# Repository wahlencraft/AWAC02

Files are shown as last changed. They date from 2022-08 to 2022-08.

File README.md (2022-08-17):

# AWAC02
An alarm clock made from scratch. The main components are ATmega328P, 2 Sparkfun Qwiic Alphanumeric Display and MCP7940M RTC. 

Work in progress. Current functionality includes:

- Show the time in 3 different formats
    - `  HH MM:SS`
    - `DDD  HH:MM`
    - `20YY MM:DD`
- Use the buttons to open a menu.
    - Change display brightness
    - Set time

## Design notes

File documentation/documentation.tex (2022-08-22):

\documentclass{awac02}

% Packages
\usepackage[utf8]{inputenc}
\usepackage{tabularx}
\usepackage{graphicx}
\usepackage{svg}
\input{tikzconfig}

\title{Documentation}
\begin{document}

\maketitle

\section{Overview}

The documentation is meant as a guide for the developer. Additional aid is
found in the source header files where most functions are documented.

\section{Source Files}

In this section an overview of the project files are given.
The files are listed in order of relevance.

\begin{centering}
\vspace{3mm}
\begin{tabularx}{.9\textwidth}{ >\raggedright p{5cm} | X }
    File(s)                  & Description \\ [0.5ex]
    \hline
    \texttt{main.c}                     & The main file. Contains the
                                          clock-mode state-machine.\\
    \texttt{constants.h}                & Global constants for defining number
                                          of displays, enabling logging etc. \\
    \texttt{menu.h}, \texttt{menu.c}    & The state machine for the menu. \\
    \texttt{utilities.h}, \texttt{utilities.c} & High level utilities. Mostly
                    for applying and showing settings. \\
    \texttt{log.h}, \texttt{log.c}      & Logging functions. Everything here
                                          will be unavailable if the LOG
                                          constant is undefined. \\
    \texttt{rtc.h}, \texttt{rtc.c}      & High level functions to set and show
                                          the external RTC clock. \\
    \texttt{display.h}, \texttt{display.c} & Low level functions to interface
                                             with the Qwiic Alphanumeric Display \\
    \texttt{helpers.h}, \texttt{helpers.c} & Simple helper-functions. \\
    \texttt{external\_interrupts.h}, \texttt{external\_interrupts.S} &
                    Register and extract the external interrupts (button
                    presses and RTC alarms). \\
    \texttt{time.h}, \texttt{time.S}    & Start and use the hardware times. \\
    \texttt{sleep.h}, \texttt{sleep.S}  & Set the processor sleep state. \\
    \texttt{twi.h}, \texttt{twi.S}      & Interface to the TWI (I2C) hardware.
                                          Read and write to external devices. \\
    \texttt{eeprom.h}, \texttt{eeprom.S} & Read and write to the EEPROM
                                           (non-volatile storage). \\
    \texttt{flash.h}, \texttt{flash.S}  & Read constant data from flash. For
                                          example an ASCII conversion table. \\
    \texttt{io.h}, \texttt{io.S}        & Direct control of pins. \\
    \texttt{usart.h}, \texttt{usart.S}  & Send data through USART. This is used
                                          to implement printf in `log.c` \\
    \texttt{math.S}                     & Low level math for assembly routines.
\end{tabularx}
\end{centering}

\section{Schematic}

In figure \ref{fig:circuit} the circuit is shown. The value of R1-R7, C1 and C5-C7
is only approximate. You can try different values. In addition to these
components two Sparkfun Qwiic Alphanumeric Displays are used. One of the
displays must be modified to disable the pull-up resistors and change the slave
address to \texttt{0x71}.

\begin{figure}[h]
    \centering
    
    \caption{The circuit (excluding displays).}
    \label{fig:circuit}
\end{figure}

\section{State Machine}

The state machine for clock mode is in \texttt{main.c} and the state machine
for the menu mode is in \texttt{menu.c}. They are implemented using the
\texttt{goto} statement which can lead to hard to understand code.  To give the
programmer a better overview of the states and make development easier some
states are documented here and shown in flow-charts. The program starts in the
\texttt{enter\_clock\_mode} state. The clock mode state machine is illustrated
in Figure \ref{fig:clock-state}.

\begin{figure}[h]
    \centering
    \input{clock-state}
    \caption{The clock mode state machine}
    \label{fig:clock-state}
\end{figure}

The menu mode state machine is a bit more complicated. A simple overview is
shown in Figure \ref{fig:menu-flowchart}. There are three basic state types in the
menu. \emph{Menu} states, \emph{choose} states and \emph{set} states. The menu
states are very simple. Each show some text on the display, then wait for a
button interrupt. If the \texttt{L} or \texttt{R} button is pressed the
state is changed to the previous or next menu state. If the \texttt{SP} button
is pressed it is changed to a choose or set state.

A choose state is used when there is multiple options for the setting that is
edited. For example when changing time. A choose state first shows the current
value of that setting, sets an RTC alarm for when it is changed and waits for
an interrupt. If the interrupt is from the RTC the new value is shown. If it is
from the \texttt{L} or \texttt{R} buttons the state changes to the previous or
next choose state. If it is from the \texttt{SP} button the state changes to
the corresponding set state.

A set state works a lot like a choose state. A RTC interrupt changes the value
shown and \texttt{SP} interrupt changes state (go back to the choose state).
But a \texttt{L} or \texttt{R} button interrupt de- or increments the value
instead.

Figure \ref{fig:choose-and-set-state} shows the program flow between a choose
and a set state in detail. The actual implementation varies slightly
between types.

\begin{figure}[h]
    \centering
    \input{choose-and-set-state}
    \caption{A choose and set state combo}
    \label{fig:choose-and-set-state}
\end{figure}

\begin{figure}[h]
    \centering
    \input{menu-flowchart}
    \label{fig:menu-flowchart}
    \caption{An overview of the menu}
\end{figure}

\end{document}

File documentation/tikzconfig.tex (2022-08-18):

\usepackage{tikz}
\usepackage{xparse}
\usetikzlibrary{positioning, fit, backgrounds, shapes, arrows.meta}

% State machine

\tikzstyle{start} = [rectangle, rounded corners, minimum width=3cm, text centered,
 draw=black, fill=red!30, inner sep=1em]

\tikzstyle{io} = [trapezium, trapezium left angle=70, trapezium right angle=110, 
 minimum height=1cm, text centered, draw=black, fill=blue!30, trapezium stretches=true,
 align=center, inner sep=1em] 

\tikzstyle{state} = [rectangle, minimum height=1cm, align=center,
      draw=black, fill=orange!30, inner sep=1em]

\tikzstyle{decision} = [ellipse, minimum width=3cm, minimum height=1cm, text centered, draw=black,
 fill=green!30, inner sep=.5em]

\tikzstyle{subprocess} = [rectangle, draw = black!50, minimum height = 2em, fill=pink!50]

\tikzstyle{process2} = [rectangle, minimum height=1cm, align=center, draw=black, fill=yellow!30, inner sep=1.8em]

\tikzstyle{process_label} = [external/.style={draw=black!50}, font={\fontsize{13pt}{12}\selectfont}]

\tikzstyle{arrow} = [thick,->,>=stealth]
\tikzstyle{slow_arrow} = [dotted, thick,->,>=stealth]
\tikzstyle{line} = [thick]

\NewDocumentCommand\StateWithBullets{m m m >{\SplitList{;}}m}{%
    \node (#1) [state, text width=6cm, #2, inner sep=5pt] {\large #3\small \begin{itemize}
    \ProcessList{#4}{\insertitem} \end{itemize}};
}
\newcommand\insertitem[1]{\item #1}

\NewDocumentCommand\JustBullets{m m >{\SplitList{;}}m}{%
    \node (#1) [state, text width=3.5cm, #2, inner sep=5pt, rounded corners,
    fill=blue!30] {\vspace{-0.8em}\small\begin{itemize}
    \ProcessList{#3}{\insertitem} \end{itemize}};
}

% Distances
\newcommand{\shortarrowlength}{3.1em}

% Menu
\tikzstyle{menu-base} = [text centered, draw=black, inner sep=0.5em, node
distance=4em, minimum height=3em, minimum width=9em]

\tikzstyle{menu-enterexit} = [menu-base, rectangle, rounded corners, fill=black!10]

\tikzstyle{menu-item} = [menu-base, rectangle, rounded corners, minimum height=3.5em]

\tikzstyle{menu-small-item} = [menu-base, rectangle, rounded corners, minimum
width=4em, minimum height=2em]

\tikzstyle{menu-setting} = [menu-base, rectangle, rounded corners, minimum
width=7em]

\tikzstyle{button-label} = [circle, draw=black, minimum size=1.3em, fill=white, inner
sep=0, line width=0.5pt, font=\footnotesize]

\tikzstyle{menu-single} = [->, >={Latex[length=2mm, width=3mm]}, line width=4pt]
\tikzstyle{menu-double} = [menu-single, <->]

\newcommand{\LRvert}[2]{%
    \draw[menu-single] ([xshift=1em]#1.south) -- node[button-label] {R}
        ([xshift=1em]#2.north);
    \draw[menu-single] ([xshift=-1em]#2.north) -- node[button-label] {L}
        ([xshift=-1em]#1.south);
}

\newcommand{\LRhor}[2]{%
    \draw[menu-single] ([yshift=0.5em]#1.east) -- node[button-label] {R}
        ([yshift=0.5em]#2.west);
    \draw[menu-single] ([yshift=-0.5em]#2.west) -- node[button-label] {L}
        ([yshift=-0.5em]#1.east);
}

\newcommand{\IncrementDecrementNode}[2]{%
    \node (_#2anchor) [#1=\shortarrowlength+1.3em of #2, outer sep=1pt, inner sep=0] {};
    \node (_#2L) [button-label, above left=0.2em of _#2anchor] {L};
    \node (_#2dec) [below left=0.2em of _#2anchor, inner sep=0, circle, minimum size=1.3em] {--};
    \node (_#2R) [button-label, above right=0.2em of _#2anchor] {R};
    \node (_#2inc) [below right=0.2em of _#2anchor, inner sep=0, circle, minimum size=1.3em] {+};
    \node (_#2set) [fit={(_#2L) (_#2R) (_#2dec) (_#2inc)}, draw] {};
}

\newcommand{\SetTimeNode}[3]{%
    \node (#1) [#2, menu-small-item] {#3};
    \IncrementDecrementNode{below}{#1}
    \draw[menu-double] (#1) -- node[button-label] {SP} (_#1set.north);
}

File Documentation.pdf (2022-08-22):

# AWAC02

# Documentation

AWAC02 | Documentation

## 1 Overview

The documentation is meant as a guide for the developer. Additional aid is found in the source header files where most functions are documented.

1

AWAC02 | Documentation

## 2 Source Files

In this section an overview of the project files are given. The files are listed in order of relevance.

File(s) | Description
main.c | The main file. Contains the clock-mode state-machine.
constants.h | Global constants for defining number of displays, enabling
| logging etc.
menu.h, menu.c | The state machine for the menu.
utilities.h, utilities.c | High level utilities. Mostly for applying and showing set-
| tings.
log.h, log.c | Logging functions. Everything here will be unavailable if
| the LOG constant is undefined.
rtc.h, rtc.c | High level functions to set and show the external RTC clock.
display.h, display.c | Low level functions to interface with the Qwiic Alphanu-
| meric Display
helpers.h, helpers.c | Simple helper-functions.
external interrupts.h, external interrupts.S | Register and extract the external interrupts (button presses
| and RTC alarms).
time.h, time.S | Start and use the hardware times.
sleep.h, sleep.S | Set the processor sleep state.
twi.h, twi.S | Interface to the TWI (I2C) hardware. Read and write to
| external devices.
eeprom.h, eeprom.S | Read and write to the EEPROM (non-volatile storage).
flash.h, flash.S | Read constant data from flash. For example an ASCII con-
| version table.
io.h, io.S | Direct control of pins.
usart.h, usart.S | Send data through USART. This is used to implement
| printf in ‘log.c‘
math.S | Low level math for assembly routines.

2

## 3 Schematic

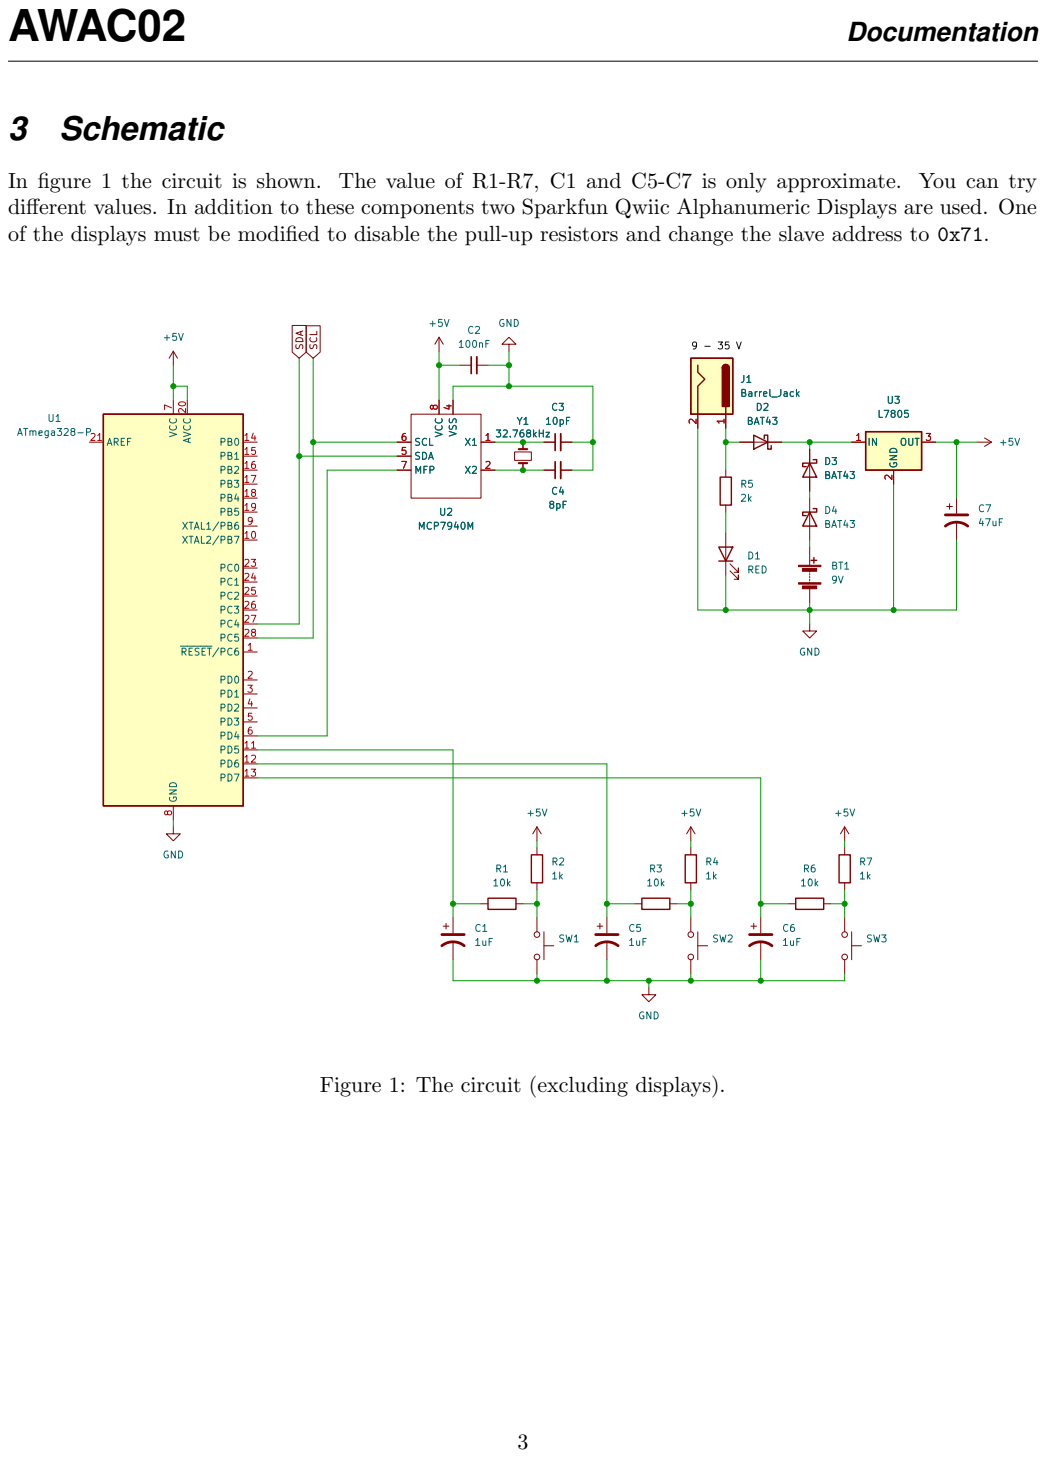
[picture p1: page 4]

In figure 1 the circuit is shown. The value of R1-R7, C1 and C5-C7 is only approximate. You can try
different values. In addition to these components two Sparkfun Qwiic Alphanumeric Displays are used. One
of the displays must be modified to disable the pull-up resistors and change the slave address to 0x71.

4 SDA 5 SCL 6 MFP 7 VCC

Figure 1: The circuit (excluding displays).

AWAC02 | Documentation

## 4 State Machine

The state machine for clock mode is in main.c and the state machine for the menu mode is in menu.c. They are implemented using the goto statement which can lead to hard to understand code. To give the programmer a better overview of the states and make development easier some states are documented here and shown in flow-charts. The program starts in the enter clock mode state. The clock mode state machine

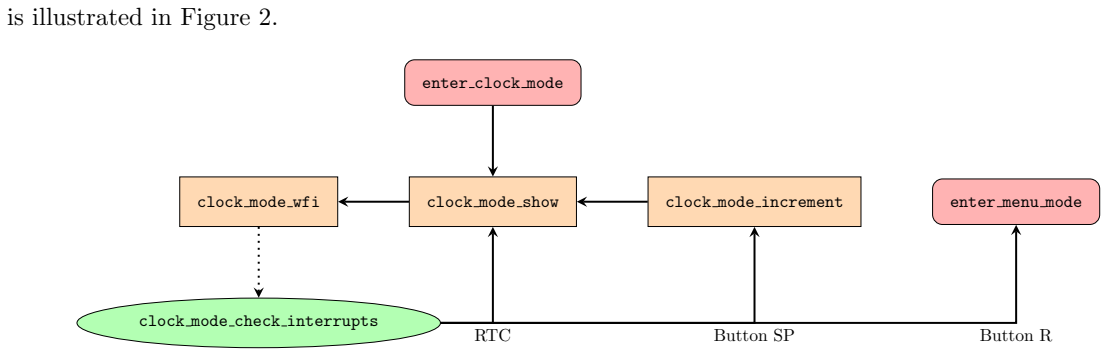
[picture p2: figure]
is illustrated in Figure 2.; clock mode show; enter clock mode; clock mode wfi; clock mode increment; clock mode check interrupts; enter menu mode; RTC; Button SP; Button R

Figure 2: The clock mode state machine

The menu mode state machine is a bit more complicated. A simple overview is shown in Figure 4. There are three basic state types in the menu. Menu states, choose states and set states. The menu states are very simple. Each show some text on the display, then wait for a button interrupt. If the L or R button is pressed the state is changed to the previous or next menu state. If the SP button is pressed it is changed to a choose or set state.
A choose state is used when there is multiple options for the setting that is edited. For example when changing time. A choose state first shows the current value of that setting, sets an RTC alarm for when it is changed and waits for an interrupt. If the interrupt is from the RTC the new value is shown. If it is from the L or R buttons the state changes to the previous or next choose state. If it is from the SP button the state changes to the corresponding set state.
A set state works a lot like a choose state. A RTC interrupt changes the value shown and SP interrupt changes state (go back to the choose state). But a L or R button interrupt de- or increments the value instead.
Figure 3 shows the program flow between a choose and a set state in detail. The actual implementation varies slightly between types.

4

AWAC02 | Documentation

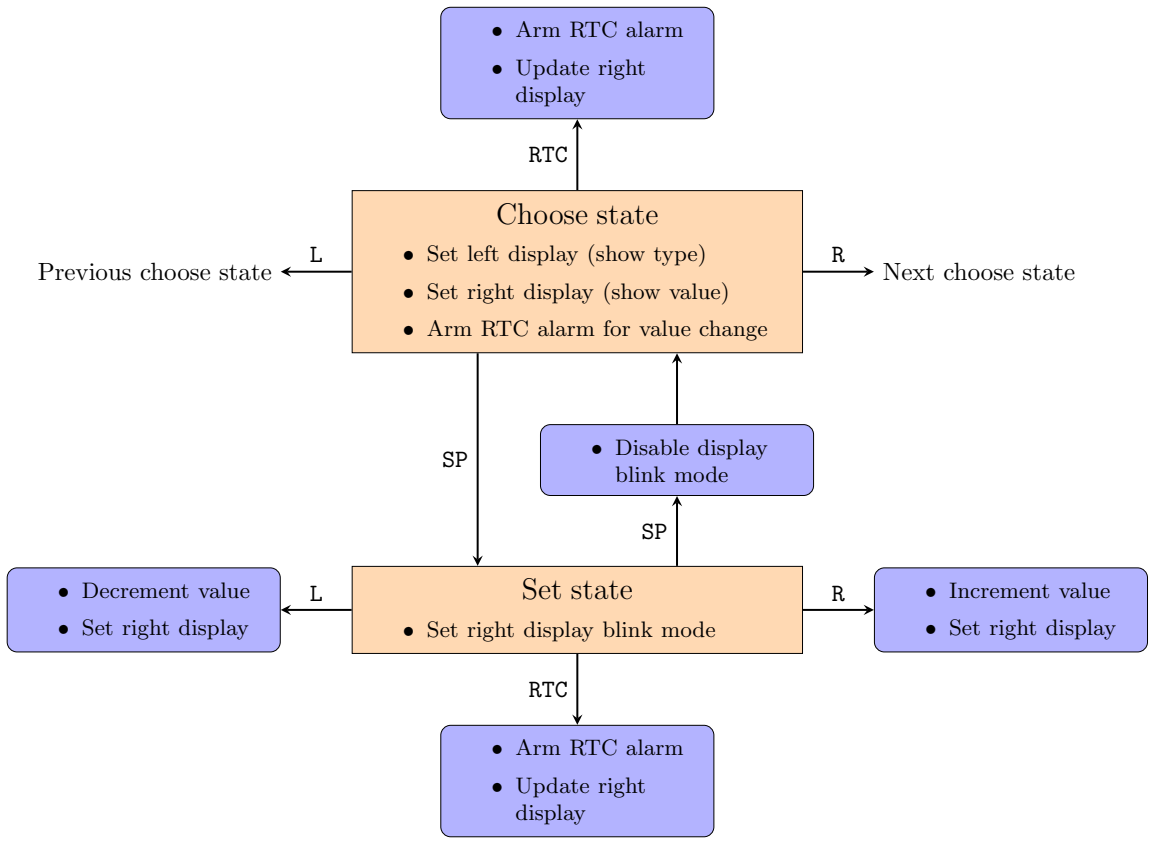
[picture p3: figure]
Choose state; • Set left display (show type); • Set right display (show value); • Arm RTC alarm for value change; • Arm RTC alarm; • Update right; display; • Disable display; blink mode; Set state; • Set right display blink mode; Previous choose state; Next choose state; • Decrement value; • Set right display; • Increment value; RTC

Figure 3: A choose and set state combo

5

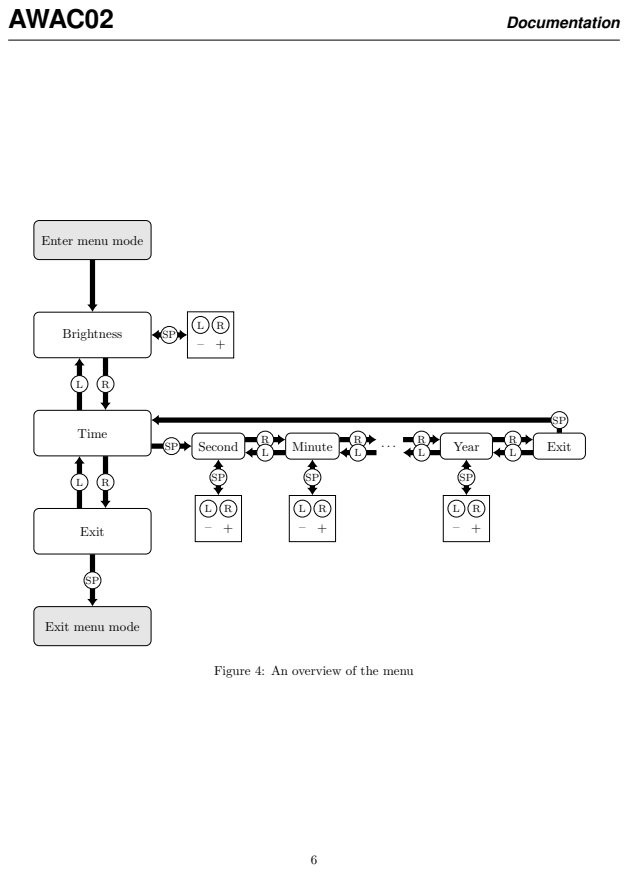
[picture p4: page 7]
AWAC02; Documentation; Brightness; Time; Exit; Second; Minute; Year; Exit R L

Enter menu mode

Exit menu mode

Figure 4: An overview of the menu

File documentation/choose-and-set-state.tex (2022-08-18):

\begin{tikzpicture}[every node/.style={scale=1}]

\StateWithBullets{CHOOSE}{draw}{Choose state}{Set left display (show type);Set
    right display (show value);Arm
RTC alarm for value change}

\JustBullets{RTC1}{above=of CHOOSE}{Arm RTC alarm; Update right display}

\JustBullets{SET_DONE}{below=of CHOOSE, xshift=4em}{Disable display blink mode}

\StateWithBullets{SET}{below=3 of CHOOSE}{Set state}{Set right display blink mode}

\node (PREVIOUS) [left=of CHOOSE] {Previous choose state};
\node (NEXT) [right=of CHOOSE] {Next choose state};

\JustBullets{DEC}{left=of SET}{Decrement value;Set right display}
\JustBullets{INC}{right=of SET}{Increment value;Set right display}
%\node (INC) [right=of SET, text width=8em] {Increment value, \\ Set right display};

\JustBullets{RTC2}{below=of SET}{Arm RTC alarm; Update right display}

% Arrows
\draw[arrow] (CHOOSE) -- node[anchor=south] {\texttt{L}} (PREVIOUS);
\draw[arrow] (CHOOSE) -- node[anchor=south] {\texttt{R}} (NEXT);
\draw[arrow] (CHOOSE) -- node[anchor=east] {\texttt{RTC}} (RTC1);

\draw[arrow] ([xshift=-4em]CHOOSE.south) -- node[anchor=east] {\texttt{SP}}
    ([xshift=-4em]SET.north);

\draw[arrow] ([xshift=4em]SET.north) -- node[anchor=east] {\texttt{SP}}
    (SET_DONE.south);
\draw[arrow] (SET_DONE.north) -- ([xshift=4em]CHOOSE.south);

\draw[arrow] (SET) -- node[anchor=south] {\texttt{L}} (DEC);
\draw[arrow] (SET) -- node[anchor=south] {\texttt{R}} (INC);
\draw[arrow] (SET) -- node[anchor=east] {\texttt{RTC}} (RTC2);

%\node (TESTNODE) [draw, text width=3cm] {Hejsvejs \newline $\bullet$ title};

%\node [font=\Large] (top)    at (5,10) {Choose state};
%\node [font=\Large] (middle) at (5,9)  {$\bullet$ [1]};
%\node [font=\Large] (bottom) at (5,8)  {$\bullet$ [2]};
%\node[draw=brown, thick,fit={(top) (middle) (bottom)}, inner sep=10pt]   (box) {};

\end{tikzpicture}

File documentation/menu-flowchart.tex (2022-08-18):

\begin{tikzpicture}[every node/.style={scale=1}]

\node (ENTER_MENU_MODE) [menu-enterexit] { Enter menu mode };

\node (MENU_BRIGHTNESS) [menu-item, below=of ENTER_MENU_MODE] { Brightness };

\IncrementDecrementNode{right}{MENU_BRIGHTNESS}
%\node(SET_BRIGHTNESS) [menu-setting, right=of MENU_BRIGHTNESS] { Set Brightness };

\node(MENU_TIME) [menu-item, below=of MENU_BRIGHTNESS] { Time };

\node(MENU_EXIT) [menu-item, below=of MENU_TIME] { Exit };

\node(EXIT_MENU_MODE) [menu-enterexit, below=of MENU_EXIT] { Exit menu mode };

% Time

\SetTimeNode{SET_SECOND}{right=\shortarrowlength of MENU_TIME,yshift=-1em}{Second};
\SetTimeNode{SET_MINUTE}{right=\shortarrowlength of SET_SECOND}{Minute};

\node (SET_DOTDOTDOT) [right=of SET_MINUTE]{\dots};

\SetTimeNode{SET_YEAR}{right=of SET_DOTDOTDOT}{Year};

\node (SET_EXIT) [menu-small-item, right=\shortarrowlength of SET_YEAR] {Exit};

% Time arrows
\LRhor{SET_SECOND}{SET_MINUTE}
\LRhor{SET_MINUTE}{SET_DOTDOTDOT}
\LRhor{SET_DOTDOTDOT}{SET_YEAR}
\LRhor{SET_YEAR}{SET_EXIT}

% Arrows between menu items
\draw[menu-single] (ENTER_MENU_MODE) -- (MENU_BRIGHTNESS);

\LRvert{MENU_BRIGHTNESS}{MENU_TIME}
\LRvert{MENU_TIME}{MENU_EXIT}

\draw[menu-single] (MENU_EXIT) -- node[button-label] {SP} (EXIT_MENU_MODE);

% Arrows to set brightness items
\draw[menu-double] (MENU_BRIGHTNESS) -- node[button-label] {SP} (_MENU_BRIGHTNESSset);

% Arrows to set time items
\draw[menu-single] ([yshift=-1em]MENU_TIME.east) -- node[button-label] {SP} (SET_SECOND);

\draw[menu-single] (SET_EXIT.north) |- node[button-label] {SP} ([yshift=1em]MENU_TIME.east);

\end{tikzpicture}

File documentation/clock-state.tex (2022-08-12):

\begin{tikzpicture}[every node/.style={scale=0.7}]

\node (CLOCK_MODE_SHOW) [state] { \texttt{clock\_mode\_show}};
\node (ENTER_CLOCK_MODE) [start, above=of CLOCK_MODE_SHOW] {\texttt{enter\_clock\_mode}};
\node (CLOCK_MODE_INCREMENT) [state, right=of CLOCK_MODE_SHOW] {\texttt{clock\_mode\_increment}};
\node (CLOCK_MODE_WFI) [state, left=of CLOCK_MODE_SHOW] {\texttt{clock\_mode\_wfi}};
\node (CLOCK_MODE_CHECK_INTERRUPTS) [decision, below=of CLOCK_MODE_WFI] {\texttt{clock\_mode\_check\_interrupts}};
\node (ENTER_MENU_MODE) [start, right=of CLOCK_MODE_INCREMENT] {\texttt{enter\_menu\_mode}};

\draw [arrow] (ENTER_CLOCK_MODE) -- (CLOCK_MODE_SHOW);

\draw [arrow] (CLOCK_MODE_CHECK_INTERRUPTS) -| node[anchor=north]{RTC}
    (CLOCK_MODE_SHOW);
\draw [arrow] (CLOCK_MODE_CHECK_INTERRUPTS) -| node[anchor=north]{Button SP} (CLOCK_MODE_INCREMENT);
\draw [arrow] (CLOCK_MODE_CHECK_INTERRUPTS) -| node[anchor=north]{Button R} (ENTER_MENU_MODE);

\draw [arrow] (CLOCK_MODE_SHOW) -- (CLOCK_MODE_WFI);
\draw [arrow] (CLOCK_MODE_INCREMENT) -- (CLOCK_MODE_SHOW);
\draw [slow_arrow] (CLOCK_MODE_WFI) -- (CLOCK_MODE_CHECK_INTERRUPTS);

\end{tikzpicture}

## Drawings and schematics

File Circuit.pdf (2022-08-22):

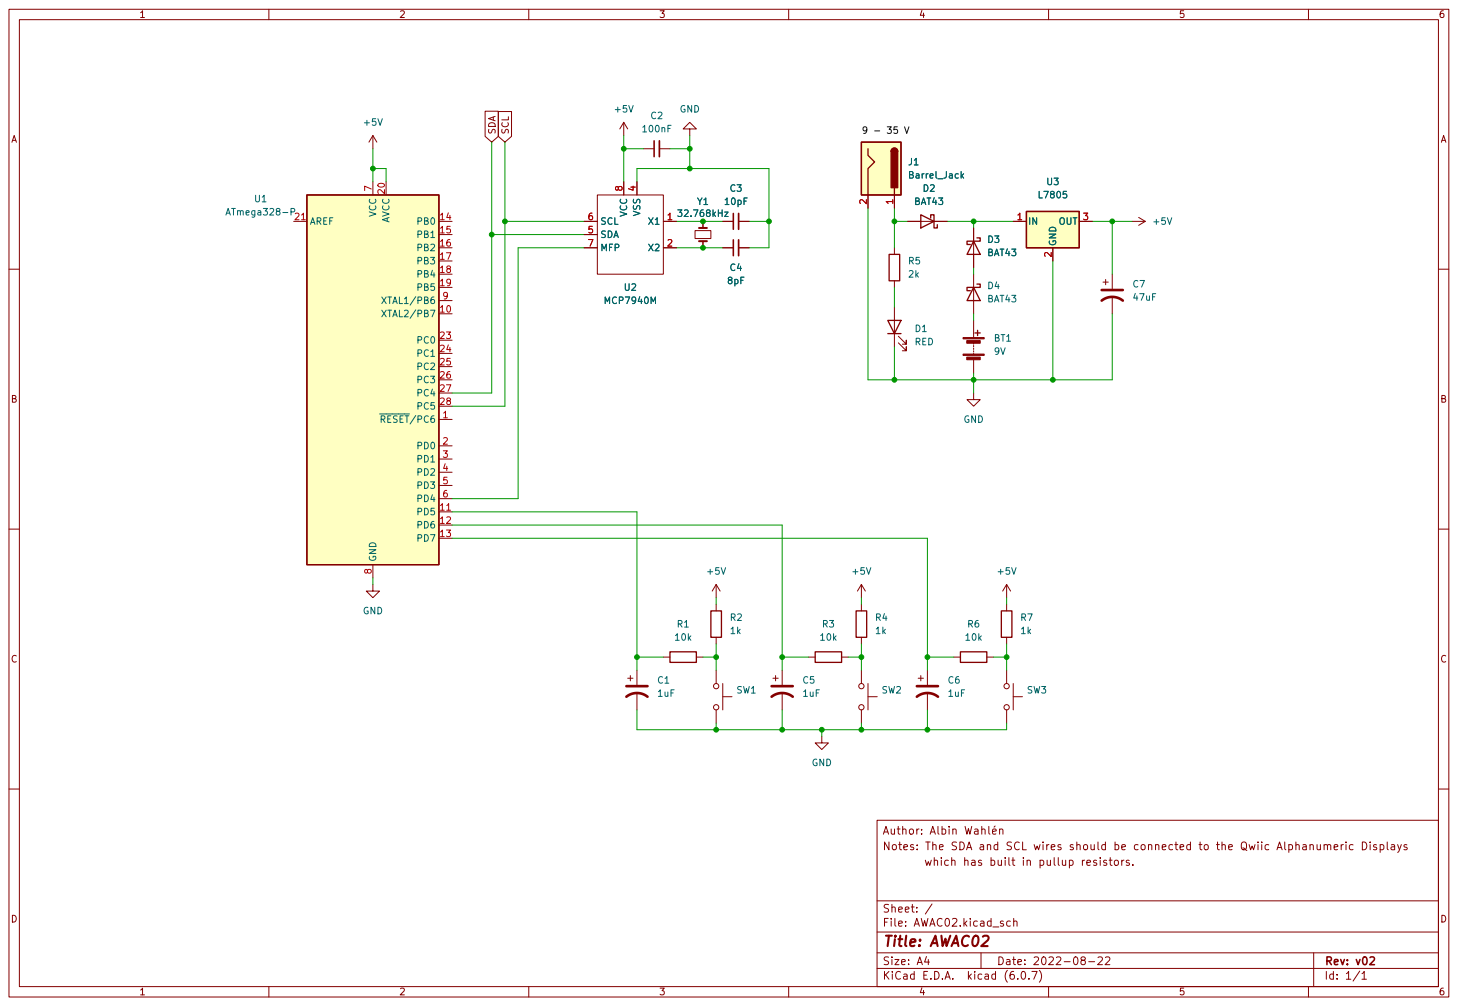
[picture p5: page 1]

4 SDA 5 SCL 6 MFP 7 VCC

Notes: The SDA and SCL wires should be connected to the Qwiic Alphanumeric Displays
which has built in pullup resistors.

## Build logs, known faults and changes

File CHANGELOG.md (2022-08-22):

# Changelog

## [0.2.0] -- 2022-08-22
### Added
- Button input
- EEPROM read/write (non-volatile storage)
- Clock mode, show the time in one of three formats:
    - `  HH MM:SS`
    - `DDD  HH:MM`
    - `20YY MM:DD`
- Menu mode:
    - Set display brightness
    - Set clock

### Changed
- The documentation is now written in LaTeX

## [0.1.0] -- 2022-07-31
### Added
- Show hours minutes and seconds since power-on.
- Backend functions to manage the display and clock.
- A schematic.

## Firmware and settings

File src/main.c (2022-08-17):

#include <stdint.h>
#include <avr/io.h>
#include <avr/interrupt.h>

#include "usart.h"
#include "time.h"
#include "io.h"
#include "twi.h"
#include "log.h"
#include "flash.h"
#include "display.h"
#include "rtc.h"
#include "external_interrupts.h"
#include "eeprom.h"
#include "sleep.h"
#include "menu.h"
#include "utilities.h"

#include "helpers.h"

extern volatile uint8_t irc_counter;

int main(void) {
    init_log(INFO | ERROR | WARNING | RTC | STATE);

    start_counter0();
    start_counter1();
    sei();

    enable();

    TWI_init();

    sleep_ms1(1);

    initiate_all_displays();
    sleep_ms1(10);

    log(INFO, "Start program\n");

    set_display_buffer_long_string("STRTPRGM", 8);
    write_to_all_displays();

    sleep_ms1(1000);

    RTC_start();

    init_external_interrupts();

    restore_display_brightness();

    log_time();

    uint8_t clock_mode = MINUTE;

    goto enter_clock_mode;

/*=============================================================================
 * CLOCK MODE
 *===========================================================================*/

enter_clock_mode:
    log(STATE, "Enter clock mode\n");
    clock_mode = MINUTE;
    goto clock_mode_show;

clock_mode_check_interrupts:
    uint8_t interrupts = extract_external_interrupts();
    log(STATE, "Clock mode: check interrupt (0x%x)\n", interrupts);
    if (interrupts & (1<<RTC_INT)) {
        goto clock_mode_show;
    }
    if (interrupts & (1<<BUTTON_SP))
        goto clock_mode_increment;
    if (interrupts & ((1<<BUTTON_L) | (1<<BUTTON_R)))
        goto enter_menu_mode;
    goto clock_mode_wfi;

clock_mode_show:
    show_time(clock_mode);
    log(STATE, "Clock mode: show\n");
    goto clock_mode_wfi;

clock_mode_increment:
    log(STATE, "Clock mode: increment\n");
    clock_mode = (clock_mode + 1) % 3;
    goto clock_mode_show;

clock_mode_wfi:
    set_alarm_next(clock_mode);
    log(STATE, "Clock mode: WFI\n");
    TWI_wait();
    sleep_until_interrupt();
    goto clock_mode_check_interrupts;

/*=============================================================================
 * MENU MODE
 *===========================================================================*/

enter_menu_mode:
    RTC_disable_alarm(ALARM0);
    menu();

    goto enter_clock_mode;
}

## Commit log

2022-07-11 Wait for current twi operation to end before starting new ones
2022-07-28 Bugfix: TWI fail when writing consecutively
    [main.c]
2022-07-31 Disable logs and remove prints
2022-08-03 Fix broken KiCad library
2022-08-03 Test button input
2022-08-03 Add push buttons to schematic
    [AWAC02.kicad_sch]
2022-08-03 Implement button input
2022-08-04 Add button input to changelog
2022-08-04 Use buttons to change clock mode
2022-08-07 Use RTC alarm as external interrupt
2022-08-22 Update circuit
    [AWAC02.kicad_sch]
